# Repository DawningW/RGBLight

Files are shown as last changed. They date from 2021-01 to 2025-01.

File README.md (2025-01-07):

# RGB Light
# 炫酷 R! G! B! 灯

基于 ESP8266/ESP32 使用 Arduino 开发的物联网小彩灯, 支持多种形态多种光效, 支持自定义动画, 配套自研网页/小程序/PC 客户端, ~~并支持 HomeAssistant 等智能家居平台~~(TODO)

产品特色:
- 支持多种产品形态: 如灯带, 圆形灯盘, 方形灯板等, 提供简单易用的接口供用户自行适配 
- 支持多种光效模式: 如常亮, 闪烁, 呼吸, 流光, 彩虹, 音乐律动等, 参数均可自定义, 自由度高
- 支持音乐律动灯效: **非通过麦克风采集声音**, 而是通过配套上位机采集手机/电脑音频, 经上位机算法计算后将结果传输到下位机, 从而实现更好的音乐律动效果
- 支持自定义灯光动画: 可播放动画, 并通过网页动画编辑器编辑动画
- 多客户端支持: 配套自研网页/小程序/PC 客户端

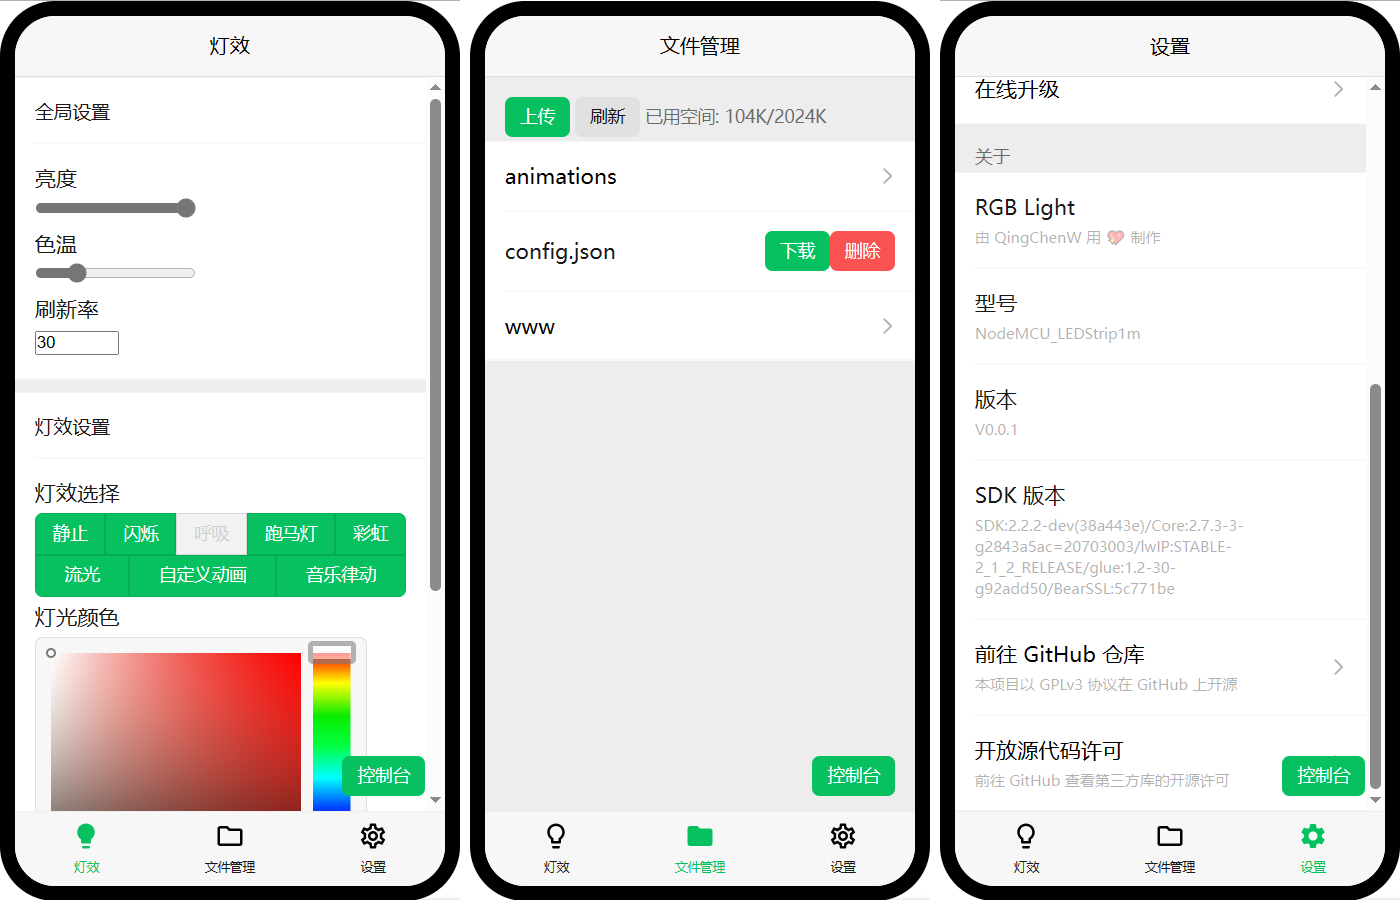
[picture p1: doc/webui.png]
网页客户端


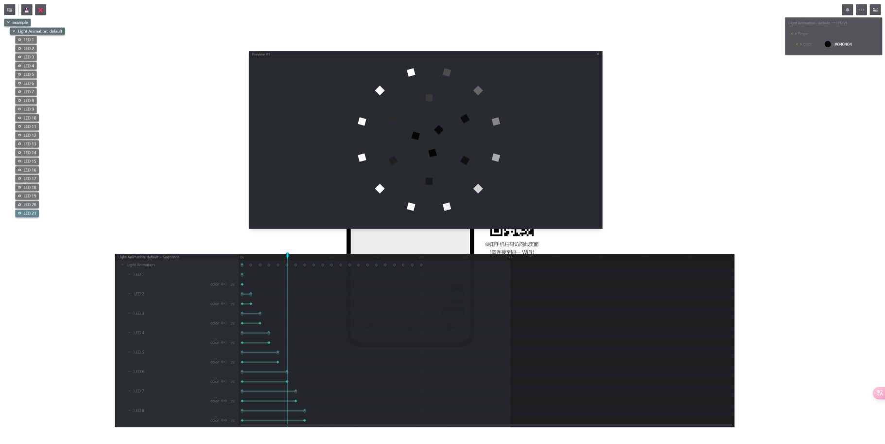
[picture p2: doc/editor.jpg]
动画编辑器


## 所需硬件
### MCU
目前已在 ESP8266/ESP32/ESP32-C3/ESP32-S3 上测试过, 理论上简单适配一下即可支持其他单片机

我使用的开发板为 WeMos D1 Mini, 使用 D4 脚连接 WS2812B

### 灯板
目前支持两种灯板:

一种为 1 米长的 WS2812B 灯带

另一种为自己画的 WS2812B 圆形灯板, 共有 21 颗灯珠, 整机最大电流 <1.5A, 原理图详见 pcb 目录

如果你想适配其他形态的灯板, 请参考下方教程

### 外壳
目前仅有投影灯形态的产品, 其模型位于 model 目录下

## 编译指南
### 安装 Arduino 和第三方库
- [ESP8266-Arduino](https://github.com/esp8266/Arduino) (esp8266)
- [arduino-esp32](https://github.com/espressif/arduino-esp32) (esp32)
- [FastLED](https://github.com/FastLED/FastLED)
- [ArduinoJSON](https://github.com/bblanchon/ArduinoJson)
- [arduinoWebSockets](https://github.com/Links2004/arduinoWebSockets)

**注意**: 如果你在 ESP8266 上遇到了第一个灯会随机闪烁的问题, 请降级 ESP8266-Arduino 至 2.7.4 版本, FastLED 降级至 3.4.0 版本, 详见 [esp8266/Arduino#8054](https://github.com/esp8266/Arduino/issues/8054)

**注意**: 如果你在 ESP32-C3 上遇到了第一个灯不亮, 其余灯随机闪烁的问题, 请更新 FastLED 至 3.7.0 版本, 详见 [FastLED/FastLED#1349](https://github.com/FastLED/FastLED/issues/1349)

### 修改配置
根据您的需求修改 config.h 中的配置

### 编译前端网页 (可选)
预编译好的前端网页已位于 data/www 目录下, 如果你不需要修改前端网页, 则可以跳过这一步

如果修改了前端页面需要自己编译, 则首先需要安装 Node.js 14 或以上版本, 然后进入 web 目录并执行以下命令:

```sh
npm install
npm run build
```

编译后的网页会自动覆盖 data/www 目录

### 编译并烧录
除了需要烧录程序以外, 还需要上传 LittleFS 文件系统, 具体教程可参考 [Uploading files to file system](https://arduino-esp8266.readthedocs.io/en/stable/filesystem.html#uploading-files-to-file-system)

Arduino IDE 2.2.1+ 可使用此插件为 RP2040/ESP8266/ESP32 上传 LittleFS 文件系统: [arduino-littlefs-upload](https://github.com/earlephilhower/arduino-littlefs-upload)

### 打包升级包
ArduinoOTA 是支持在线升级文件系统的, 但是遗憾的是并不支持差量更新, 为了不丢失用户配置和自定义动画等数据, 我选择把 bin 和资源文件打包为单个二进制文件, 再由上位机进行解析更新

运行根目录下的 `pack_ota_bin.py` 即可打包升级包 (需要 Python 3.8 或以上版本), 生成的升级包位于 `build/upgrade.bin`, 然后使用网页前端的`在线升级`功能即可升级

## 适配其他灯板
见 Light.hpp

## 新增灯效
见 LightEffect.hpp

## 音乐律动模式
在使用设备自带的网页端的音乐律动模式时, 若提示 `因浏览器策略限制无法启动音频采集` 时, 请前往[chrome://flags/#unsafely-treat-insecure-origin-as-secure](chrome://flags/#unsafely-treat-insecure-origin-as-secure) 将 `Insecure origins treated as secure` 设置为 `Enabled` 并添加设备网页 url 链接到列表中, 然后重启浏览器即可

## 自定义灯光动画
打开设备网页端, 进入文件管理页面, 再进入 animations 文件夹, 点击右下角的加号悬浮按钮即可新增动画, 点击动画文件上的编辑按钮即可编辑该动画

打开动画编辑器后, 点击左侧大纲中的任意元素即可打开序列窗口, 在序列窗口中可设置关键帧及过渡, 按下空格键可以预览动画, 制作完成后点击左上方保存按钮进行保存, 点击关闭按钮关闭动画编辑器

## 版权声明
本项目代码采用 GPLv3 协议开源, 允许商用, 但商用必须遵循 GPLv3 协议提供给客户完整源代码. 自制的灯板及外壳模型保留所有权利

动画编辑器来自于 [theatre-js/theatre](https://github.com/theatre-js/theatre), AGPLv3

本项目在开发的过程中也参考了一些其他项目, 在此一并致以感谢:
- [WLED](https://github.com/Aircoookie/WLED)

祝姐姐妹妹生日快乐!

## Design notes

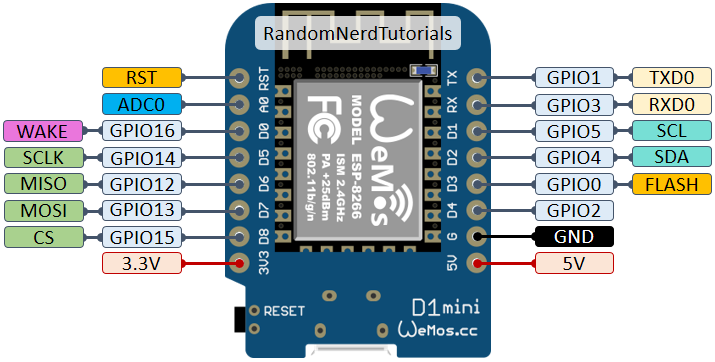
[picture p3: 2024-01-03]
pcb/WeMos-D1-Mini-pinout.png

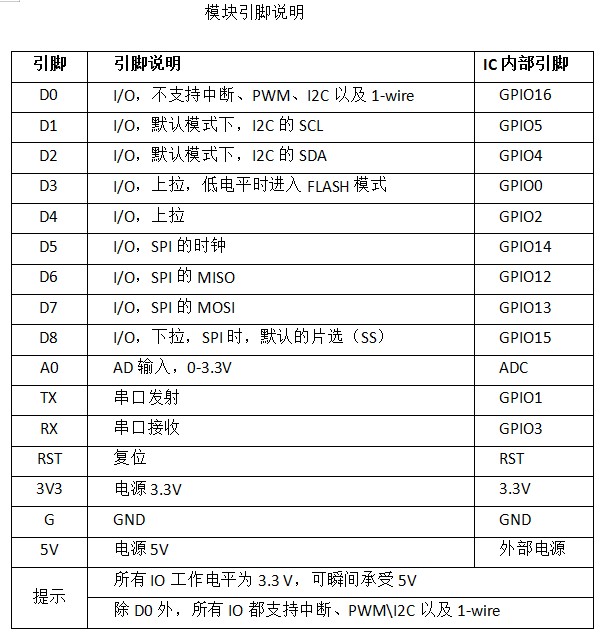
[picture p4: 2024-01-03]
pcb/WeMos-D1-Mini-pinout-desc.JPG

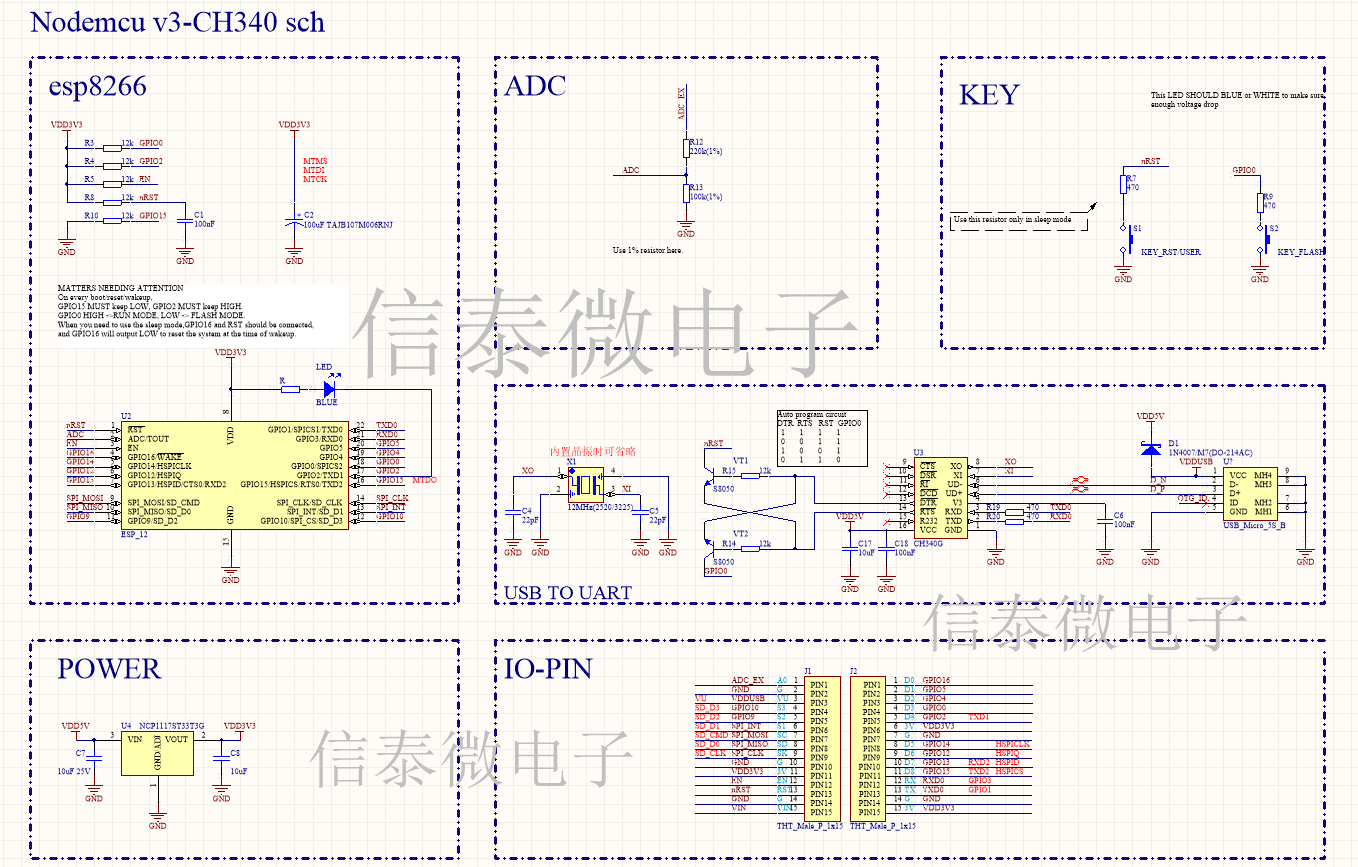
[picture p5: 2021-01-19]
pcb/NodeMCU-pcb.png

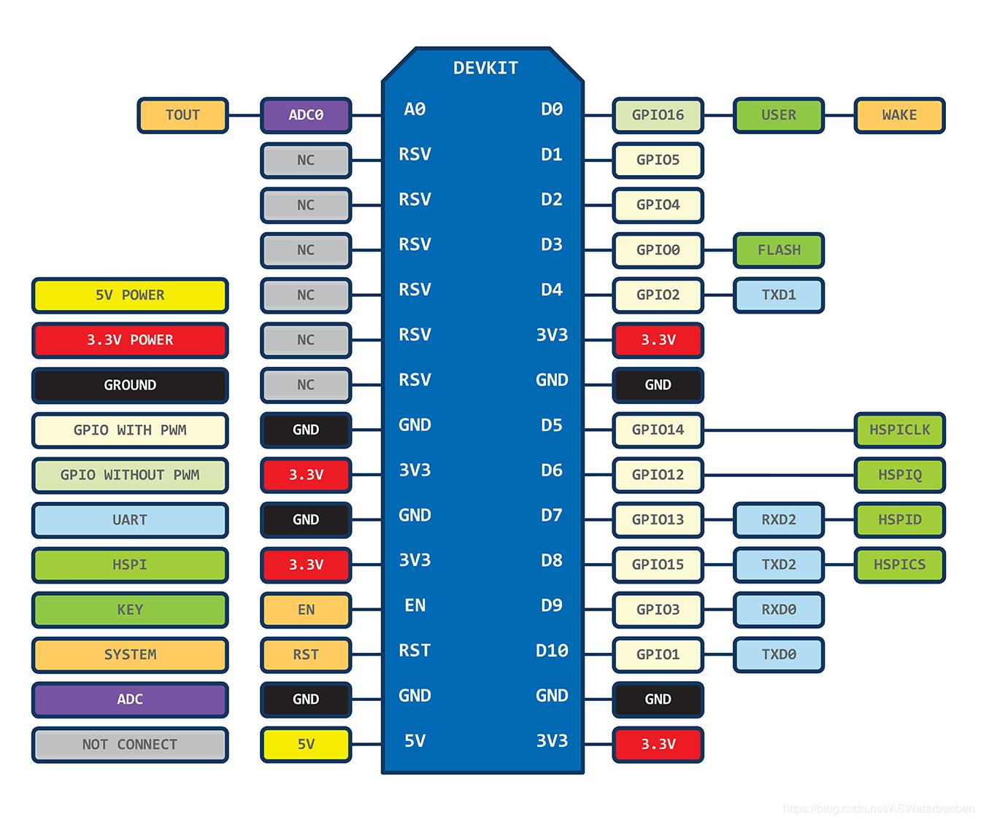
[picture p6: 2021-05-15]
pcb/NodeMCU-pins.png

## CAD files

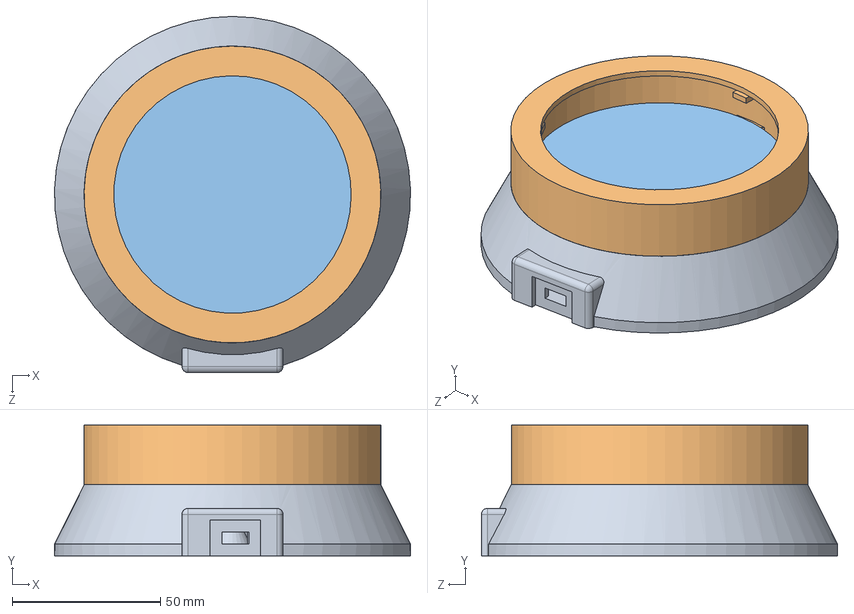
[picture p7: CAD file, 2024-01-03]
model/投影灯.SLDASM
120.0 x 44.0 x 120.0 mm
投影灯下部
投影灯上部
灯板^投影灯

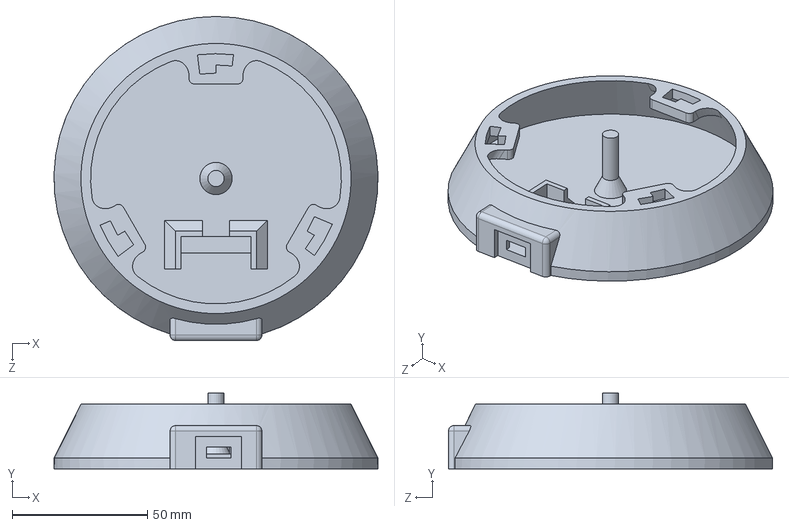
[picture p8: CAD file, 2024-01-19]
model/投影灯下部.SLDPRT
120.0 x 28.0 x 120.0 mm

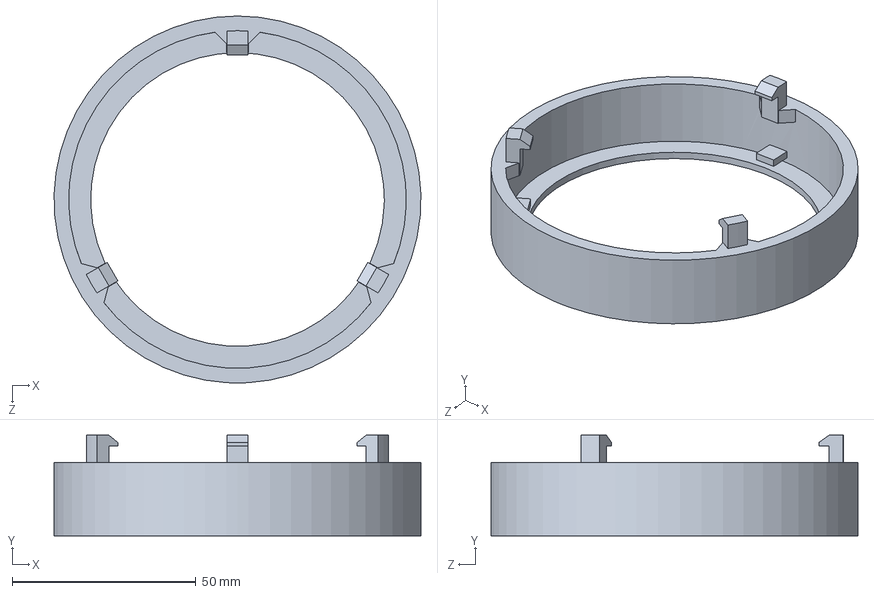
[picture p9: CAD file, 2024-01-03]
model/投影灯上部.SLDPRT
100.0 x 27.4 x 100.0 mm

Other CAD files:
model/投影灯上部.STL
model/投影灯下部.STL

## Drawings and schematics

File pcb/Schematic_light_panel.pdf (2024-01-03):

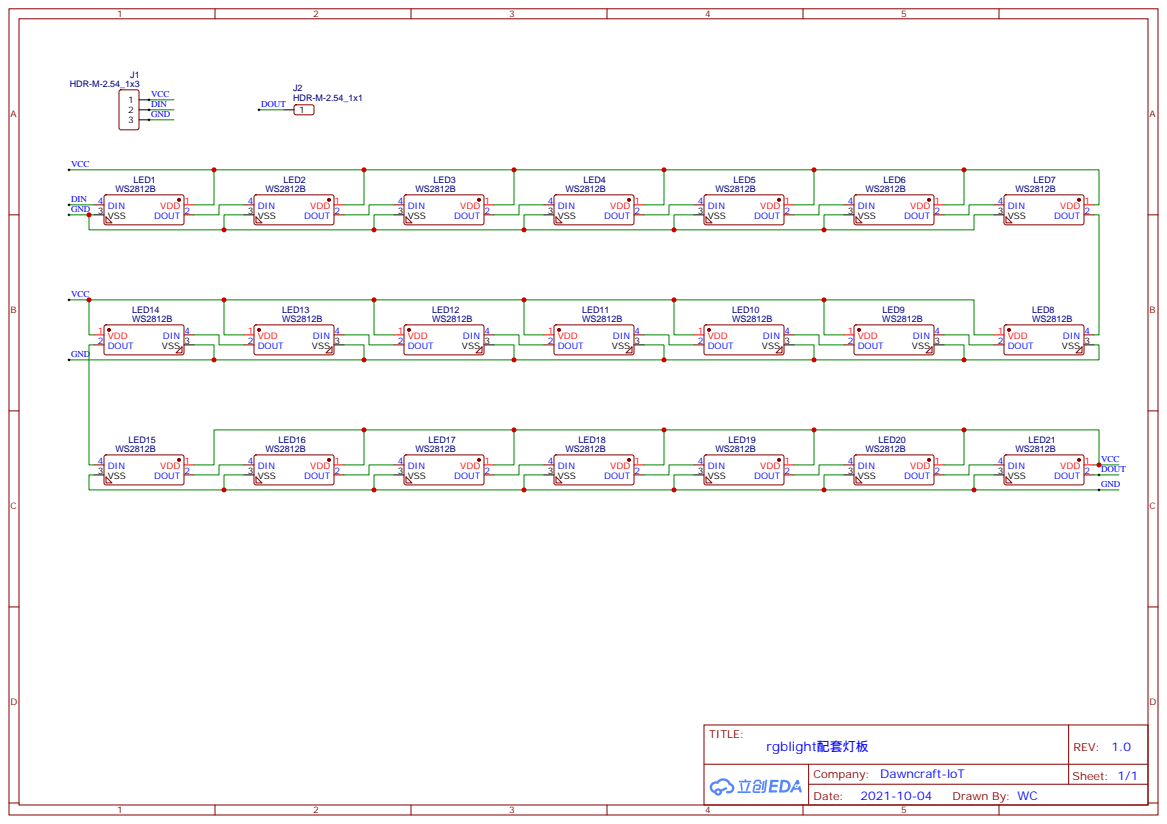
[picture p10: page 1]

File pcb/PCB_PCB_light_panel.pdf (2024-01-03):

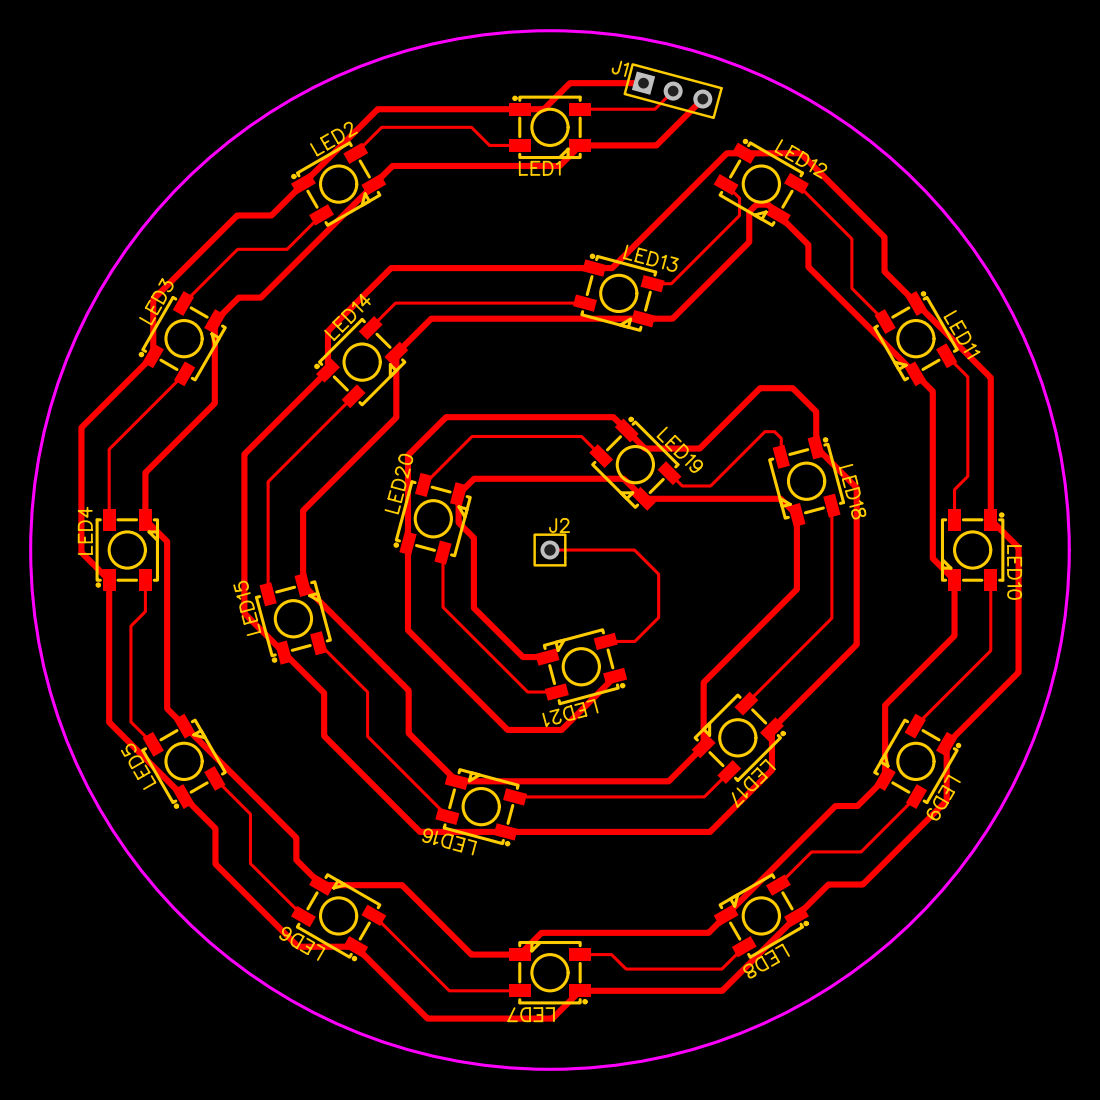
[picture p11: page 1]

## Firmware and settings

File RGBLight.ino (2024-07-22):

/**
 * RGB Light 炫酷 RGB 灯
 *
 * 基于 ESP8266/ESP32 使用 Arduino 开发的物联网炫酷小彩灯, 支持多种形态多种光效, 配套自研网页/小程序/PC 客户端
 *
 * @author QingChenW
 */

#include "config.h"

#include <functional>
#include <Arduino.h>
#include <Ticker.h>
#include <LittleFS.h>
#if defined(ESP8266)
#include <Updater.h>
#elif defined(ESP32)
#include <Update.h>
#endif
#include <DNSServer.h>
#if defined(ESP8266)
#include <ESP8266WiFi.h>
#include <ESP8266mDNS.h>
#include <ESP8266WebServer.h>
typedef ESP8266WebServer WebServer;
#elif defined(ESP32)
#include <WiFi.h>
#include <ESPmDNS.h>
#include <WebServer.h>
#include <detail/mimetable.h>
#endif
#include <WiFiUdp.h>
#include <WebSocketsServer.h>
#include <ArduinoJson.h>
#define FASTLED_ESP8266_RAW_PIN_ORDER // 不需要转换
#include <FastLED.h>
#ifdef ENABLE_DEBUG
#include <GDBStub.h>
#endif

#include "CommandHandler.hpp"
#include "Light.hpp"
#include "LightEffect.hpp"
#include "utils.h"

#define MIME_TYPE(t) (mime::mimeTable[mime::type::t].mimeType)

typedef std::function<Effect*(int argc, const char *argv[])> CreateEffectFunc;

const char *product_name = "rgblight";
const char *model_name = MODEL;
const char *version = VERSION;
const uint32_t version_code = VERSION_CODE;

CreateEffectFunc effectFactories[EFFECT_TYPE_COUNT];
Ticker timer;
LIGHT_TYPE light;
Effect *lightEffect;
DNSServer dnsServer;
WebServer webServer(80);
WebSocketsServer wsServer(81);

struct Config {
    time_t lastModifyTime;
    bool isDirty;

    String name;          // 设备名称
    String ssid;          // WIFI 名称
    String password;      // WIFI 密码
    String hostname;      // 主机名
    uint16_t refreshRate; // 刷新率, 默认 60Hz
    uint8_t brightness;   // 亮度, 默认 63
    uint32_t temperature; // 色温, 默认 6600K
} config;

// For LightEffect
const uint16_t &fps = config.refreshRate;

void markDirty() {
    config.lastModifyTime = millis();
    config.isDirty = true;
}

void serializeSettings(JsonDocument &doc, bool includeWifi = true) {
    doc["name"] = config.name;
    if (includeWifi) { // 获取 wifi 信息时不应包含密码
        doc["ssid"] = config.ssid;
        doc["password"] = config.password;
    }
    doc["hostname"] = config.hostname;
    doc["refreshRate"] = config.refreshRate;
    doc["brightness"] = config.brightness;
    doc["temperature"] = config.temperature;
    lightEffect->writeToJSON(doc);
}

void saveSettings() {
    Serial.println(F("Save settings"));
    StaticJsonDocument<1024> doc;
    doc["version"] = version_code;
    serializeSettings(doc);
    File file = LittleFS.open("/config.json", "w");
    if (!serializeJson(doc, file)) {
        Serial.println(F("Save settings failed"));
    }
    file.close();
    config.isDirty = false;
}

void readSettings() {
    Serial.println(F("Read settings"));
    bool shouldSave = false;
    StaticJsonDocument<1024> doc;
    if (!LittleFS.exists("/config.json")) {
        Serial.println(F("Setting not found, create new"));
        shouldSave = true;
    } else {
        File file = LittleFS.open("/config.json", "r");
        DeserializationError error = deserializeJson(doc, file);
        file.close();
        if (error) {
            Serial.print(F("Read settings failed: "));
            Serial.println(error.f_str());
            shouldSave = true;
        }
    }
    if (doc["version"] != version_code) {
        Serial.printf_P(PSTR("Update settings from %d to %d\n"), doc["version"].as<int>(), version_code);
        shouldSave = true;
    }
    config.name = doc["name"] | NAME;
    config.ssid = doc["ssid"].as<const char *>();
    config.password = doc["password"].as<const char *>();
    config.hostname = doc["hostname"] | product_name;
    config.refreshRate = doc["refreshRate"] | 60;
    config.brightness = doc["brightness"] | 63;
    config.temperature = doc["temperature"] | 6600;
    lightEffect = Effect::readFromJSON<LIGHT_TYPE>(doc);

    FastLED.setBrightness(config.brightness);
    FastLED.setTemperature(CRGB(kelvin2rgb(config.temperature)));
    timer.attach_ms(1000 / config.refreshRate, updateLight);
    
    if (shouldSave) {
        saveSettings();
    }
}

// 2.7.4 版本 MDNS 服务需要绑定到接口, 所以在每次切换接口时重启 MDNS 服务
void setWifiMode(WiFiMode_t mode) {
    dnsServer.stop();
    MDNS.end();

    WiFi.mode(mode);
    WiFi.hostname(config.hostname);
    delay(100);

    if (mode == WIFI_AP) {
        Serial.println(F("Start DNS server"));
        dnsServer.setErrorReplyCode(DNSReplyCode::NoError);
        if (dnsServer.start(53, "*", WiFi.softAPIP())) {
            Serial.println(F("DNS server started"));
        }
    }
    Serial.println(F("Start mDNS"));
    if (MDNS.begin(config.hostname)) {
        MDNS.addService("http", "tcp", 80);
        // MDNS.addService("ws", "tcp", 81);
        MDNS.addServiceTxt("http", "tcp", "product", product_name);
        MDNS.addServiceTxt("http", "tcp", "version", version);
        MDNS.addServiceTxt("http", "tcp", "name", config.name);
        Serial.println(F("MDNS responder started"));
    }
}

int scanWifi(JsonArray &array) {
    Serial.println(F("Start to scan wifi"));
    int n = WiFi.scanNetworks();
    if (n > 0) {
        Serial.printf_P(PSTR("%d wifi(s) found:\n"), n);
        for (int i = 0; i < n; ++i) {
            JsonObject obj = array.createNestedObject();
            obj["ssid"] = WiFi.SSID(i);
            obj["rssi"] = WiFi.RSSI(i);
            obj["type"] = WiFi.encryptionType(i);
            Serial.printf_P(PSTR("%d: %s (%d)%c\n"), i + 1, WiFi.SSID(i).c_str(), WiFi.RSSI(i),
                (WiFi.encryptionType(i) == 0) ? ' ' : '*');
        }
    } else {
        Serial.println(F("No wifi found"));
    }
    Serial.println(F("Scan wifi finished"));
    return n;
}

bool connectWifi(const String &ssid, const String &password) {
    Serial.println(F("Connecting to wlan"));
    if (ssid.isEmpty()) {
        Serial.println(F("Wifi SSID is empty"));
        return false;
    }
    WiFi.begin(ssid, password);
    time_t t = millis();
    while (WiFi.status() != WL_CONNECTED) {
        delay(500);
        Serial.print(".");
        if (millis() - t > 10 * 1000) {
            Serial.println();
            Serial.println(F("Can't connect to wlan"));
            return false;
        }
    }
    Serial.println();
    Serial.print(F("Connect to wlan successfully, IP: "));
    Serial.println(WiFi.localIP());
    return true;
}

bool startHotspot() {
    Serial.println(F("Start wifi hotspot"));
    bool result = WiFi.softAP(config.name);
    if (result) {
        Serial.print(F("Start hotspot successfully, IP: "));
        Serial.println(WiFi.softAPIP());
    } else {
        Serial.println(F("Can't start hotspot"));
    }
    return result;
}

void updateLight() {
    if (lightEffect->update(light, 0)) {
        FastLED.show();
    }
}

void handleCommand(SenderFunc sender, char *line) {
    if (lightEffect->type() == MUSIC) {
        if (!isalpha(line[0])) { // 假定所有命令都是字母开头且以字母开头的一定是命令
            ((MusicEffect<LIGHT_TYPE> *) lightEffect)->setVolume(atof(line));
            return;
        }
    } else if (lightEffect->type() == CUSTOM) {
        if (!isalpha(line[0])) {
            uint32_t color = str2hex(line);
            int &index = ((CustomEffect<LIGHT_TYPE> *) lightEffect)->getIndex();
            light.data()[index++] = CRGB(color);
            if (index >= light.count()) {
                index = 0;
            }
            return;
        }
    }
    cmdHandler.parseCommand(sender, line);
}

void initEffects() {
    effectFactories[CONSTANT] = [](int argc, const char *argv[]) {
        uint32_t color = argc > 0 ? str2hex(argv[0]) : DEFAULT_COLOR;
        return new ConstantEffect<LIGHT_TYPE>(color);
    };
    effectFactories[BLINK] = [](int argc, const char *argv[]) {
        uint32_t color = argc > 0 ? str2hex(argv[0]) : DEFAULT_COLOR;
        float lastTime = argc > 1 ? atof(argv[1]) : 1.0;
        float interval = argc > 2 ? atof(argv[2]) : 1.0;
        return new BlinkEffect<LIGHT_TYPE>(color, lastTime, interval);
    };
    effectFactories[BREATH] = [](int argc, const char *argv[]) {
        uint32_t color = argc > 0 ? str2hex(argv[0]) : DEFAULT_COLOR;
        float lastTime = argc > 1 ? atof(argv[1]) : 1.0;
        float interval = argc > 2 ? atof(argv[2]) : 0.5;
        return new BreathEffect<LIGHT_TYPE>(color, lastTime, interval);
    };
    effectFactories[CHASE] = [](int argc, const char *argv[]) {
        uint32_t color    = argc > 0 ? str2hex(argv[0]) : DEFAULT_COLOR;
        uint8_t direction = argc > 1 ? atoi(argv[1]) : 0;
        float lastTime    = argc > 2 ? atof(argv[2]) : 0.2;
        return new ChaseEffect<LIGHT_TYPE>(color, direction, lastTime);
    };
    effectFactories[RAINBOW] = [](int argc, const char *argv[]) {
        int8_t delta = argc > 0 ? atoi(argv[0]) : 1;
        return new RainbowEffect<LIGHT_TYPE>(delta);
    };
    effectFactories[STREAM] = [](int argc, const char *argv[]) {
        uint8_t direction = argc > 0 ? atoi(argv[0]) : 0;
        int8_t delta      = argc > 1 ? atoi(argv[1]) : 1;
        return new StreamEffect<LIGHT_TYPE>(direction, delta);
    };
    effectFactories[ANIMATION] = [](int argc, const char *argv[]) {
        const char *name = argc > 0 ? argv[0] : "";
        return new AnimationEffect<LIGHT_TYPE>(name);
    };
    effectFactories[MUSIC] = [](int argc, const char *argv[]) {
        uint8_t mode = argc > 0 ? atoi(argv[0]) : 1;
        return new MusicEffect<LIGHT_TYPE>(mode);
    };
    effectFactories[CUSTOM] = [](int argc, const char *argv[]) {
        return new CustomEffect<LIGHT_TYPE>();
    };
}

void registerCommands() {
    cmdHandler.setDefaultHandler([](SenderFunc sender, int argc, char *argv[]) {
        sender("Unknown command. type 'help' for helps.");
    });
    cmdHandler.registerCommand("help", "Show command helps", [](SenderFunc sender, int argc, char *argv[]) {
        cmdHandler.printHelp(sender);
    });
#ifdef ENABLE_DEBUG
    cmdHandler.registerCommand("debug", "Show debug info", [](SenderFunc sender, int argc, char *argv[]) {
        printSystemInfo();
        printWifiInfo();
    });
#endif
    cmdHandler.registerCommand("version", "Show version", [](SenderFunc sender, int argc, char *argv[]) {
        StaticJsonDocument<256> doc;
        doc["product"] = product_name;
        doc["model"] = model_name;
#if defined(ESP8266)
        doc["id"] = ESP.getChipId();
#elif defined(ESP32)
        doc["id"] = ESP.getEfuseMac();
#endif
        doc["version"] = version;
        doc["versionCode"] = version_code;
#if defined(ESP8266)
        doc["sdkVersion"] = ESP.getFullVersion();
#elif defined(ESP32)
        doc["sdkVersion"] = ESP.getSdkVersion();
#endif
        String str;
        serializeJson(doc, str);
        sender(str.c_str());
    });
    cmdHandler.registerCommand("status", "Show status", [](SenderFunc sender, int argc, char *argv[]) {
        StaticJsonDocument<256> doc;
#if defined(ESP8266)
        doc["vcc"] = ESP.getVcc() / 1000.0;
        doc["resetReason"] = ESP.getResetReason();
        doc["freeHeap"] = ESP.getFreeHeap();
        doc["heapFragment"] = ESP.getHeapFragmentation();
        doc["maxFreeBlock"] = ESP.getMaxFreeBlockSize();
#elif defined(ESP32)
        doc["resetReason"] = esp_reset_reason();
        doc["freeHeap"] = ESP.getFreeHeap();
        doc["heapMaxFreeBlock"] = ESP.getMaxAllocHeap();
        doc["freePsram"] = ESP.getFreePsram();
        doc["psramMaxFreeBlock"] = ESP.getMaxAllocPsram();
#endif
        doc["RSSI"] = WiFi.RSSI();
#if defined(ESP8266)
        FSInfo fs_info;
        LittleFS.info(fs_info);
        doc["fsTotalSpace"] = fs_info.totalBytes;
        doc["fsUsedSpace"] = fs_info.usedBytes;
#elif defined(ESP32)
        doc["fsTotalSpace"] = LittleFS.totalBytes();
        doc["fsUsedSpace"] = LittleFS.usedBytes();
#endif
        String str;
        serializeJson(doc, str);
        sender(str.c_str());
    });
    cmdHandler.registerCommand("config", "Get config", [](SenderFunc sender, int argc, char *argv[]) {
        StaticJsonDocument<1024> doc;
        if (WiFi.getMode() == WIFI_AP) {
#if defined(ESP8266)
            struct ip_info info;
            wifi_get_ip_info(SOFTAP_IF, &info);
            doc["ssid"] = emptyString;
            doc["ip"] = IPAddress(info.ip.addr).toString();
            doc["mask"] = IPAddress(info.netmask.addr).toString();
            doc["gateway"] = IPAddress(info.gw.addr).toString();
#elif defined(ESP32)
            doc["ssid"] = WiFi.softAPSSID();
            doc["ip"] = WiFi.softAPIP().toString();
            doc["mask"] = WiFi.softAPSubnetMask().toString();
            doc["gateway"] = WiFi.softAPIP().toString();
#endif
        } else {
            doc["ssid"] = WiFi.SSID();
            doc["ip"] = WiFi.localIP().toString();
            doc["mask"] = WiFi.subnetMask().toString();
            doc["gateway"] = WiFi.gatewayIP().toString();
        }
        serializeSettings(doc, false);
        String str;
        serializeJson(doc, str);
        sender(str.c_str());
    });
    cmdHandler.registerCommand("scan", "Scan wifi", [](SenderFunc sender, int argc, char *argv[]) {
        DynamicJsonDocument doc(1024);
        JsonArray array = doc.to<JsonArray>();
        scanWifi(array);
        String str;
        serializeJson(doc, str);
        sender(str.c_str());
    });
    cmdHandler.registerCommand("connect", "Connect to wifi", [](SenderFunc sender, int argc, char *argv[]) {
        if (argc <= 1) {
            sender("INVAILD");
            return;
        }
        String ssid(argv[1]);
        String password(argc > 2 ? argv[2] : "");
        if (connectWifi(ssid, password)) {
            sender(WiFi.localIP().toString().c_str());
            setWifiMode(WIFI_STA);
            config.ssid = ssid;
            config.password = password;
            markDirty();
        } else {
            sender("ERR");
            if (WiFi.getMode() == WIFI_STA && !connectWifi(config.ssid, config.password)) {
                startHotspot();
                setWifiMode(WIFI_AP);
            }
        }
    });
    cmdHandler.registerCommand("disconnect", "Disconnect from wifi", [](SenderFunc sender, int argc, char *argv[]) {
        startHotspot();
        sender("OK");
        setWifiMode(WIFI_AP);
        config.ssid = "";
        config.password = "";
        markDirty();
    });
    cmdHandler.registerCommand("name", "Get/set device name", [](SenderFunc sender, int argc, char *argv[]) {
        if (argc <= 1) {
            String str = config.name + String(',') + config.hostname;
            sender(str.c_str());
            return;
        }
        config.name = argv[1];
        if (argc > 2) config.hostname = argv[2];
        markDirty();
        sender("OK");
        if (WiFi.getMode() == WIFI_AP) {
            startHotspot();
        }
        setWifiMode(WiFi.getMode());
    });
    cmdHandler.registerCommand("mode", "Get/set light mode", [](SenderFunc sender, int argc, char *argv[]) {
        if (argc <= 1) {
            String str = effect2str(lightEffect->type());
            sender(str.c_str());
            return;
        }
        EffectType type = str2effect(argv[1]);
        if (type >= CONSTANT && type < EFFECT_TYPE_COUNT) {
            delete lightEffect;
            lightEffect = effectFactories[type](argc - 2, (const char **) argv + 2);
            markDirty();
            sender("OK");
        } else {
            sender("INVAILD");
        }
    });
    cmdHandler.registerCommand("brightness", "Get/set brightness", [](SenderFunc sender, int argc, char *argv[]) {
        if (argc <= 1) {
            String str = String(config.brightness);
            sender(str.c_str());
            return;
        }
        int brightness = atoi(argv[1]);
        if (brightness >= 0 && brightness <= 255) {
            if (config.brightness != brightness) {
                FastLED.setBrightness(brightness);
                FastLED.show();
                config.brightness = (uint8_t) brightness;
                markDirty();
            }
            sender("OK");
        } else {
            sender("INVAILD");
        }
    });
    cmdHandler.registerCommand("temperature", "Get/set temperature", [](SenderFunc sender, int argc, char *argv[]) {
        if (argc <= 1) {
            String str = String(config.temperature) + String('K');
            sender(str.c_str());
            return;
        }
        int temperature = atoi(argv[1]);
        if (temperature >= 0) {
            if (config.temperature != temperature) {
                FastLED.setTemperature(CRGB(kelvin2rgb(temperature)));
                FastLED.show();
                config.temperature = (uint32_t) temperature;
                markDirty();
            }
            sender("OK");
        } else {
            sender("INVAILD");
        }
    });
    cmdHandler.registerCommand("fps", "Get/set refresh rate", [](SenderFunc sender, int argc, char *argv[]) {
        if (argc <= 1) {
            String str = String(config.refreshRate);
            sender(str.c_str());
            return;
        }
        int rate = atoi(argv[1]);
        if (rate > 0 && rate <= 400) {
            if (config.refreshRate != rate) {
                if (timer.active()) timer.detach();
                timer.attach_ms(1000 / rate, updateLight);
                config.refreshRate = (uint16_t) rate;
                markDirty();
            }
            sender("OK");
        } else {
            sender("INVAILD");
        }
    });
}

#ifdef ESP8266
ADC_MODE(ADC_VCC); // Enable ESP.getVcc()
#endif
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
void loop() {
    if (config.isDirty && millis() - config.lastModifyTime >= CONFIG_SAVE_PERIOD) {
        saveSettings();
    }
    while (Serial.available() > 0) {
        char buffer[128];
        size_t len = Serial.readBytesUntil('\n', buffer, sizeof(buffer) - 1);
        if (len > 0) {
            buffer[len] = '\0';
#ifdef ENABLE_DEBUG
            Serial.printf("Received data from com: %s\n", buffer);
#endif
            handleCommand([](const char *msg) {
                Serial.println(msg);
            }, buffer);
            yield();
        }
    }
    dnsServer.processNextRequest();
    webServer.handleClient();
    wsServer.loop();
#if defined(ESP8266)
    MDNS.update();
#endif
}

#ifdef ENABLE_DEBUG
void printSystemInfo() {
    Serial.println("----- System Information -----");
#if defined(ESP8266)
    Serial.printf("Supply voltage: %.3fV\r\n", ESP.getVcc() / 1000.0);
    Serial.printf("Reset reason: %s\r\n", ESP.getResetReason().c_str());
    Serial.printf("Chip ID: %u\r\n", ESP.getChipId());
    Serial.printf("Core version: %s\r\n", ESP.getCoreVersion().c_str());
    Serial.printf("SDK version: %s\r\n", ESP.getSdkVersion());
    Serial.printf("CPU Freq: %dMHz\r\n", ESP.getCpuFreqMHz());
    Serial.printf("Free heap: %u\r\n", ESP.getFreeHeap());
    Serial.printf("Heap fragment percent: %d%%\r\n", ESP.getHeapFragmentation());
    Serial.printf("Max free block size: %d\r\n", ESP.getMaxFreeBlockSize());
    Serial.printf("Sketch size: %u\r\n", ESP.getSketchSize());
    Serial.printf("Sketch free space: %u\r\n", ESP.getFreeSketchSpace());
    Serial.printf("Sketch MD5: %s\r\n", ESP.getSketchMD5().c_str());
    Serial.printf("Flash chip ID: %u\r\n", ESP.getFlashChipId());
    Serial.printf("Flash chip size: %u\r\n", ESP.getFlashChipSize());
    Serial.printf("Flash chip real size: %u\r\n", ESP.getFlashChipRealSize());
    Serial.printf("Flash chip speed: %u\r\n", ESP.getFlashChipSpeed());
    Serial.printf("Cycle count: %u\r\n", ESP.getCycleCount());
#endif
}

void printWifiInfo() {
    Serial.println("----- WIFI Information -----");
    Serial.printf("Current mode: %d\r\n", WiFi.getMode());
    Serial.println("----- STA Info -----");
    Serial.printf("Connected: %s\r\n", WiFi.isConnected() ? "true" : "false");
    const char *wifi_status;
    switch (WiFi.status()) {
        case WL_IDLE_STATUS: wifi_status = "Idle";
        case WL_NO_SSID_AVAIL: wifi_status = "No SSID";
        case WL_SCAN_COMPLETED: wifi_status = "Scan Done";
        case WL_CONNECTED: wifi_status = "Connected";
        case WL_CONNECT_FAILED: wifi_status = "Failed";
        case WL_CONNECTION_LOST: wifi_status = "Lost";
        case WL_DISCONNECTED: wifi_status = "Disconnected";
        default: wifi_status = "Other";
    }
    Serial.printf("Connection status: %s\r\n", wifi_status);
    Serial.printf("Auto connect: %s\r\n", WiFi.getAutoConnect() ? "true" : "false");
    Serial.printf("MAC address: %s\r\n", WiFi.macAddress().c_str());
    Serial.printf("Hostname: %s\r\n", WiFi.hostname().c_str());
    Serial.printf("SSID: %s\r\n", WiFi.SSID().c_str());
    Serial.printf("PSK: %s\r\n", WiFi.psk().c_str());
    if (WiFi.status() == WL_CONNECTED) {
        Serial.printf("Local IP: %s\r\n", WiFi.localIP().toString().c_str());
        Serial.printf("Subnet mask: %s\r\n", WiFi.subnetMask().toString().c_str());
        Serial.printf("Gateway IP: %s\r\n", WiFi.gatewayIP().toString().c_str());
        Serial.printf("DNS 1: %s\r\n", WiFi.dnsIP(0).toString().c_str());
        Serial.printf("DNS 2: %s\r\n", WiFi.dnsIP(1).toString().c_str());
        Serial.printf("BSSID: %s\r\n", WiFi.BSSIDstr().c_str());
        Serial.printf("RSSI: %d\r\n", WiFi.RSSI());
    }
    Serial.println("----- AP Info -----");
    Serial.printf("Station count: %d\r\n", WiFi.softAPgetStationNum());
    Serial.printf("AP IP: %s\r\n", WiFi.softAPIP().toString().c_str());
    Serial.printf("AP MAC: %s\r\n", WiFi.softAPmacAddress().c_str());
    softap_config config;
    if (wifi_softap_get_config(&config)) {
        Serial.printf("SSID: %s\r\n", config.ssid);
        Serial.printf("Password: %s\r\n", config.password);
        Serial.printf("Channel: %d\r\n", config.channel);
        Serial.printf("Auth mode: %d\r\n", config.authmode);
        Serial.printf("Hidden: %d\r\n", config.ssid_hidden);
        Serial.printf("Max connections: %d\r\n", config.max_connection);
        Serial.printf("Beacon interval: %d\r\n", config.beacon_interval);
    }
}
#endif

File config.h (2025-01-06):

#ifndef __CONFIG_H__
#define __CONFIG_H__

// 型号, 用于检查更新, 如果你使用其他开发板请修改型号, 避免被小程序推送更新
#define MODEL "NodeMCU_LEDStrip1m" // 1 米灯带版本 (30 个 WS2812B 灯珠)
// #define MODEL "D1_mini_WCLightPanel" // 投影灯版本, 原理图详见 pcb 文件夹
// #define MODEL "NodeMCU_LightCube" // 16 * 16 光立方版本 (WIP)
// 版本号
#define VERSION "V0.3.0"
// 版本代码, 用于检查更新
#define VERSION_CODE 4

/****************************** 硬件配置 ******************************/
// LED 灯数据引脚
#define LED_DATA_PIN 4 // D2 GPIO4
// LED 灯型号, 详见 FastLED 文档
#define LED_TYPE WS2812B
// LED 灯颜色顺序, 详见 FastLED 文档
#define LED_COLOR_ORDER GRB
// LED 灯颜色校正(可选), 详见 FastLED 文档
// #define LED_CORRECTION 0xFFFFFF
// LED 灯功率限制(可选), 详见 FastLED 文档
#define LED_MAX_POWER_MW 2500
// LED 灯形态, 详见 Light.hpp
#define LIGHT_TYPE LightStrip<30, false>
// #define LIGHT_TYPE LightDisc<CLOCKWISE | OUTSIDE_IN, 12, 6, 3>
// #define LIGHT_TYPE LightPanel<16, 16, Z_WORD | HORIZONTAL>

/****************************** 软件配置 ******************************/
// 开启调试模式
// #define ENABLE_DEBUG
// 给你的炫酷小彩灯起个名字吧, 会影响 WIFI 热点名称和网页/小程序的显示
#define NAME "RGBLight"
// 多少毫秒不修改配置后保存配置, 0 为每次修改后立刻保存 (建议不要设为 0, 会大大缩短 Flash 寿命)
#define CONFIG_SAVE_PERIOD (10 * 1000)

// 恭喜你, 已经完成了所有配置, 其余配置可通过网页或小程序修改, 详见 README.md

#endif // __CONFIG_H__

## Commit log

2021-01-19 Update sisters' light
    [上部.STL, 下部.STL]
2021-01-19 Add rgblight
    [animation.csv]
2021-03-19 Update SSDP
    [animation.csv]
2021-04-04 Refactory rgblight mode
    1. 添加fps设置命令
    2. name命令可用于设置hostname
    3. connect命令可使用静态ip地址
    4. 加入音乐律动和上位机控制模式
    5. 移除color命令
    6. 重构mode命令
    [animation.csv]
2021-04-12 Add 中景园STM32F104开发板 test
2021-05-02 Update stm32f103
2021-05-02 Update rgblight.ino
    static_cast不能用于指针和指针之间的转换
2021-05-15 Update stm32f407
2024-01-03 重写 RGBLight
    [PCB_light_panel.pcbdoc, example.csv, light_panel.schdoc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]
2024-01-03 修复大小写问题
2024-01-03 修复前端音乐律动
2024-01-06 实现设置界面
2024-01-07 升级包打包脚本
2024-01-07 实现在线升级功能 文件管理页面添加已用空间 修复首次启动时默认灯光颜色为黑色的bug
2024-01-07 放宽功率限制至2.5W(5V 0.5A)
2024-01-11 实现更好的音乐律动算法
2024-01-17 修复切换网络后MDNS不工作的问题
2024-01-18 现在修改设备名称后立刻生效, 无需重启设备
2024-01-18 更新前端页面
2024-01-19 修正投影灯模型 开发板的底座短了1毫米......
    [投影灯下部.SLDPRT, 投影灯下部.STL]
2024-02-23 完善音乐律动模式相关界面
2024-03-18 初步适配ESP32
2024-07-22 ESP32适配完成
2025-01-06 实现动画编辑器
    [example.csv]
2025-01-07 实现圆形灯板动画编辑
2025-01-07 修复动画模式下刷新页面选中的动画丢失的bug
